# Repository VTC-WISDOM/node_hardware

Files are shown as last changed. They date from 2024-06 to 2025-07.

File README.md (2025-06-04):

# hardware
a collection of schematic and pcb designs for the WiSDOM node
unless otherwise specified, everything contained in this repository is licensed under the CERN Open Hardware License version 2 - Weakly Reciprocal License (CERN-OHL-W).
this is comparable to the gpl2, see LICENSE for details

## Using this repo
using your favorite package manager, install kicad-footprints and kicad-symbols alongside kicad. this is the best way to get the standard libraries. if you for some reason cannot do so, see the linked official kicad libraries in kicad-libs/footprints and kicad-libs/symbols.
in the kicad symbol editor, go to preferences -> manage symbol libraries and select "add existing", navigate to the kicad-libs/symbols directory and select the symbol libraries contained therein. repeat this with the symbols contained in kicad-libs/JLCPCB-Kicad-Library.
repeat this for footprints.

### node-rp2040
stores all of the relevant design files for the WiSDOM node that is based on the RP2040

### node-rp2350
like above but the RP2350

### other
test projects, antenna and transmission equipment, etc. anything unspecified

### docs
will add as much documentation as possible!

## Node V6 (RP2040)

changes:
- removed 5v regulator
- changed rp2040 xtal to the recommended part due to availability
- changed the sim card slot due to availability
- reviewed other parts and made changes to ensure full availability from both JLC and Digikey
- changed footprints over to JLC library footprints
- major layout changes- pin headers now broken out in two halves, etc - look at the pcb for a full description
- removed jst connectors (evil) and replaced them with barrel jacks
- mounting holes now m2.5 instead of m2

## Node V5 (RP2040)
 ***SIM7080G NON-FUNCTIONAL***

change since previous version:
- added USBLC6 esd protection on the usb line
- added CAT24 eeprom ic
- removed options for rtc to stick with just the PCF8523
- added SP3485 for RS485 / MODBUS communication
- added u.fl connector for the ism radio
- changed to narrower profile pushbuttons for run/bootsel
- added additional reset switch to interrupt 3.3V to the board entirely (used to reset the device to a known state for all components including the radios)
- yet more improvements to routing
- updated design to be mostly assembled by JLC pcb fab available components

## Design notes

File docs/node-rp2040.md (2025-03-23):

## V4
v4.0.2: schematic split into sheets for organization
        added better switching circuit for usb/bat operation. replaced 3.3V supply with a linear regulator for stability and reverse voltage protection. 
        includes first prototype of footprints for cellular interface. cellular functionality is not guaranteed until further testing.
        better layout of RP2040 traces. added jst connectors for battery and external power(labeled solar).  
        only "v4\_0\_2" files will be tested. assume others should not be used.

## V3
v3.0: never built. don't use.
v3.1: discovered issue with RP2040 crystal, requiring 1k series resistance
v3.2: discovered issue with switching between external and battery power causing the RP2040 to enter a locked state.
      troubleshooted MCP7940 RTC and determined it will not communicate with the RP2040 for unknown reasons
      added 5.1k resistors on usb-c cc lines
      battery & power circuitry is insufficient and risks damaging pc usb outputs if battery is reversed. no overcharge protection
      retired, do not use

## V2
v2: second prototype, used only for testing radio communications. 
    retired, do not use

## V1
v1: initial prototype. retired, do not use

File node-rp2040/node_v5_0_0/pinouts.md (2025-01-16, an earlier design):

| RP2040 GPIO | External Connection | Function/Peripheral | Remarks |
| --- | --- | --- | --- |
| 0 | | SIM7080G TX0 | |
| 1 | | SIM7080G RX0 | |
| 2 | | PCF8523 MFP1 | |
| 3 | | PCF8523 MFP2 | |
| 4 | SDA | I2C0 SDA | RTC & EEPROM on this i2c |
| 5 | SCL | I2C0 SCL | RTC & EEPROM on this i2c |
| 6 | | SP3485 DE | |
| 7 | | SP3485 !RE | |
| 8 | TX1 | SP3485 DI | sp3485 on this uart |
| 9 | RX1 | SP3485 RO | sp3485 on this uart |
| 10 | | RFM69 DIO0 | |
| 11 | | RFM69 DIO1 | |
| 12 | | | not connected. |
| 13 | | 5V REG ENABLE | |
| 14 | | SIM7080G PWRKEY | |
| 15 | | SIM7080G DTR | |
| 16 | MISO | SPI0 MISO | |
| 17 | | RFM69 CS | |
| 18 | CLK | SPI0 CLK | |
| 19 | MOSI | SPI0 MOSI | |
| 20 | | RFM69 RST | |
| 21 | CS | | can be any GPIO func. |
| 22 | | RFM69 DIO2 | |
| 23 | | RFM69 DIO3 | |
| 24 | | RFM69 DIO4 | |
| 25 | | RFM69 DIO5 | |
| 26 | | VBAT SAMPLE | 1/2 voltage divider from VBAT |
| 27 | GP27 (ADC1) | | |
| 28 | GP28 (ADC2) | | |
| 29 | GP29 (ADC3) | | |

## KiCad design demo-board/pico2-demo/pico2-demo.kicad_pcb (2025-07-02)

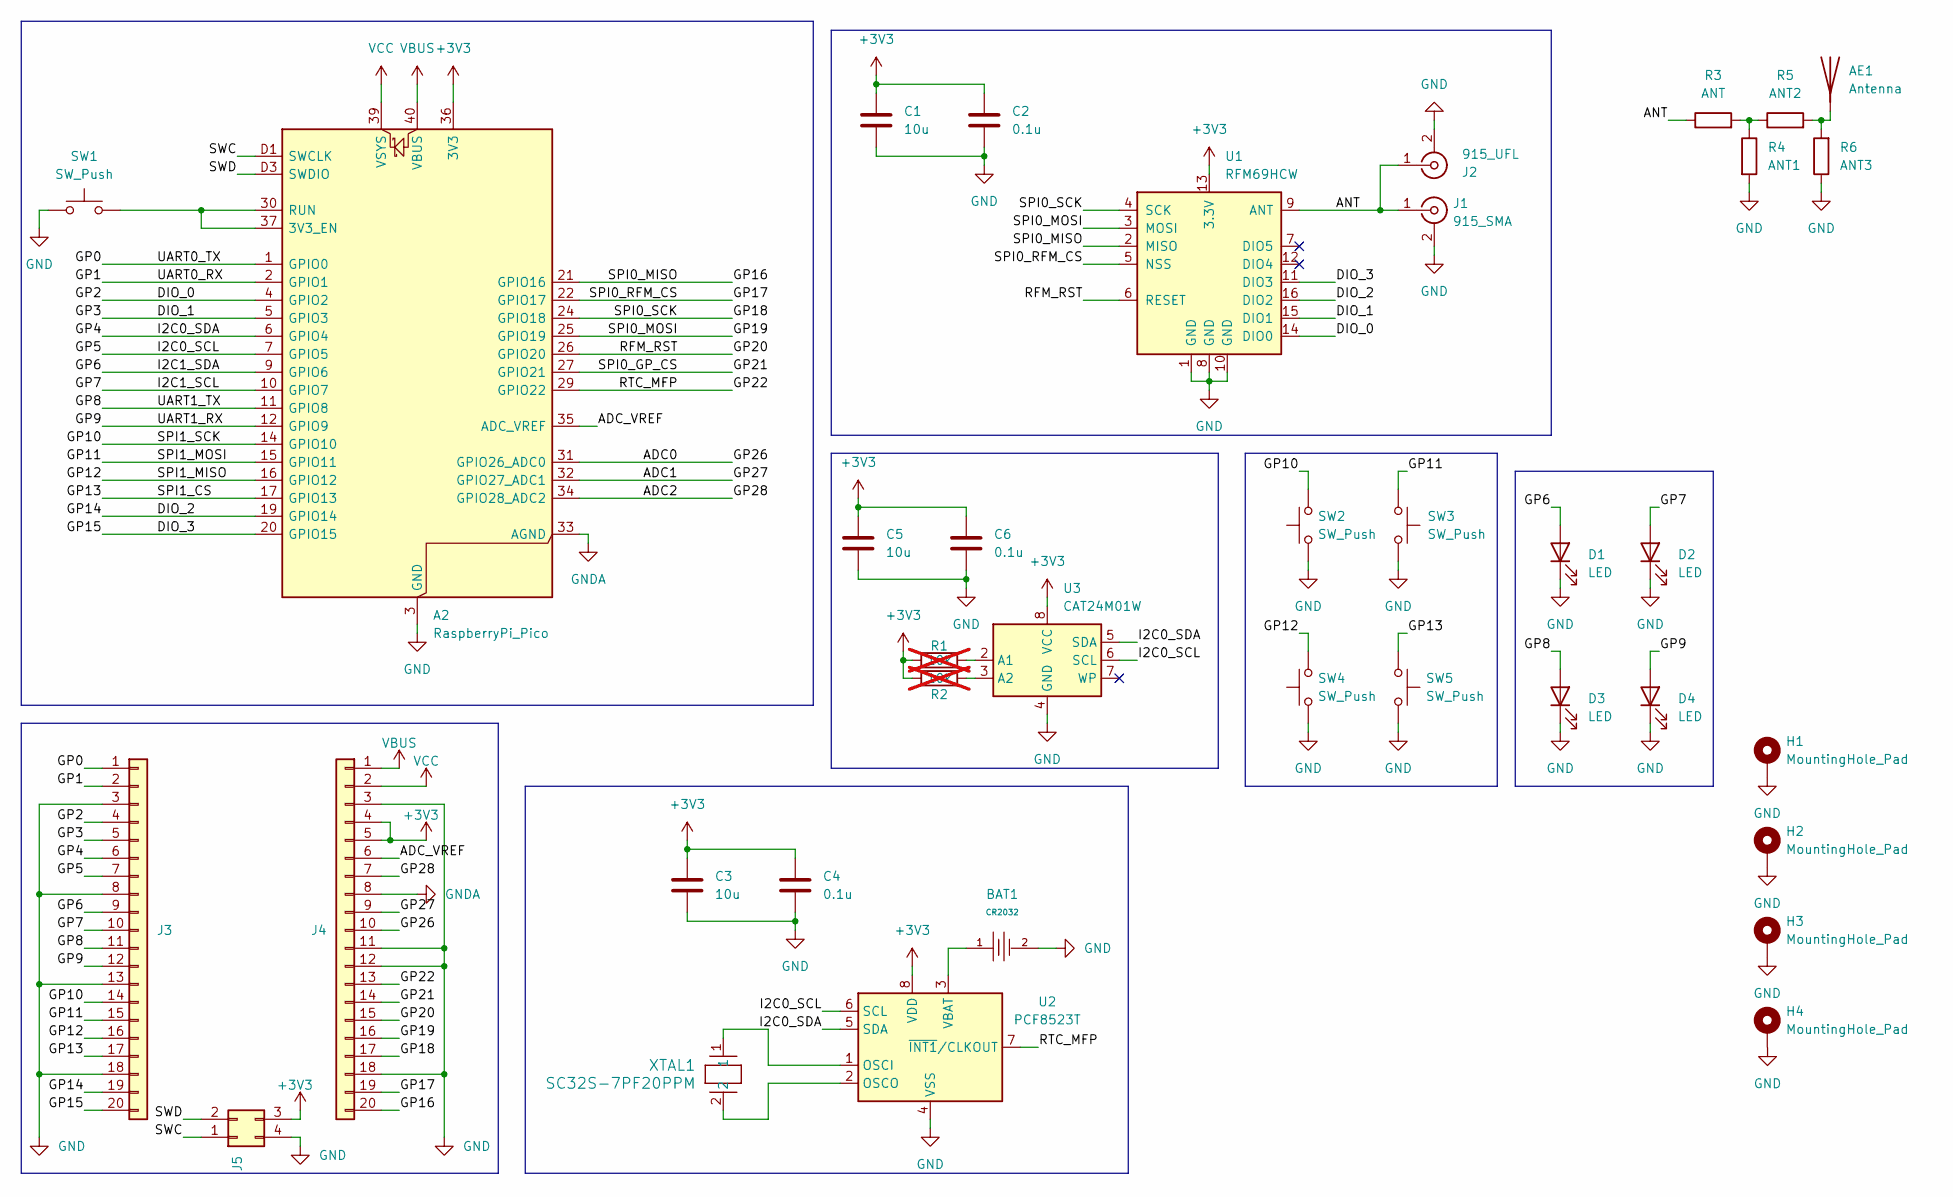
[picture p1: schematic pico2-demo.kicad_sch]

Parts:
A2: RaspberryPi_Pico; RaspberryPi_Pico_SMD_HandSolder
AE1: Antenna; Texas_SWRA416_868MHz_915MHz
BAT1: CR2032; BAT_BAT-HLD-001-THM; Part BS-07-A1BJ001; LCSC C2979167
C1, C3, C5: 10u; C_0805_2012Metric_Pad1.18x1.45mm_HandSolder
C2, C4, C6: 0.1u; C_0402_1005Metric_Pad0.74x0.62mm_HandSolder
D1, D2, D3, D4: LED; LED_1206_3216Metric_Pad1.42x1.75mm_HandSolder
H1, H2, H3: MountingHole_Pad; MountingHole_3.2mm_M3_Pad
H4: MountingHole_Pad; MountingHole_3.2mm_M3
J1: 915_SMA; SMA_Samtec_SMA-J-P-H-ST-EM1_EdgeMount
J2: 915_UFL; U.FL_Molex_MCRF_73412-0110_Vertical
J3, J4: Conn_01x20; PinHeader_1x20_P2.54mm_Vertical
J5: Conn_02x02_Counter_Clockwise; PinHeader_2x02_P2.54mm_Vertical
R1, R2: 10k; R_0805_2012Metric_Pad1.20x1.40mm_HandSolder; not fitted
R3: ANT; R_0805_2012Metric_Pad1.20x1.40mm_HandSolder
R4: ANT1; C_0402_1005Metric_Pad0.74x0.62mm_HandSolder
R5: ANT2; C_0402_1005Metric_Pad0.74x0.62mm_HandSolder
R6: ANT3; C_0402_1005Metric_Pad0.74x0.62mm_HandSolder
SW1, SW2, SW3, SW4, SW5: SW_Push; SW_PUSH_6mm
U1: RFM69HCW; HOPERF_RFM9XW_SMD
U2: PCF8523T; SOIC-8_3.9x4.9mm_P1.27mm
U3: CAT24M01W; SOIC-8_3.9x4.9mm_P1.27mm
XTAL1: SC32S-7PF20PPM; XTAL_SC32S-7PF20PPM_EPS

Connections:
+3V3: A2.36 (3V3), C1.1, C2.1, C3.1, C4.1, C5.1, C6.1, J4.4, J4.5, J5.3, R1.1, R2.1, U1.13 (3.3V), U2.8 (VDD), U3.8 (VCC)
/ADC0: A2.31 (GPIO26_ADC0), J4.10
/ADC1: A2.32 (GPIO27_ADC1), J4.9
/ADC2: A2.34 (GPIO28_ADC2), J4.7
/ADC_VREF: A2.35 (ADC_VREF), J4.6
/ANT: J1.1 (In), J2.1 (In), R3.1, U1.9 (ANT)
/DIO_0: A2.4 (GPIO2), J3.4, U1.14 (DIO0)
/DIO_1: A2.5 (GPIO3), J3.5, U1.15 (DIO1)
/DIO_2: A2.19 (GPIO14), J3.19, U1.16 (DIO2)
/DIO_3: A2.20 (GPIO15), J3.20, U1.11 (DIO3)
/GP0: A2.1 (GPIO0), J3.1
/GP1: A2.2 (GPIO1), J3.2
/GP4: A2.6 (GPIO4), J3.6, U2.5 (SDA), U3.5 (SDA)
/GP5: A2.7 (GPIO5), J3.7, U2.6 (SCL), U3.6 (SCL)
/GP6: A2.9 (GPIO6), D1.2 (A), J3.9
/GP7: A2.10 (GPIO7), D2.2 (A), J3.10
/GP8: A2.11 (GPIO8), D3.2 (A), J3.11
/GP9: A2.12 (GPIO9), D4.2 (A), J3.12
/GP10: A2.14 (GPIO10), J3.14, SW2.2
/GP11: A2.15 (GPIO11), J3.15, SW3.1
/GP12: A2.16 (GPIO12), J3.16, SW4.2
/GP13: A2.17 (GPIO13), J3.17, SW5.1
/GP16: A2.21 (GPIO16), J4.20, U1.2 (MISO)
/GP17: A2.22 (GPIO17), J4.19, U1.5 (NSS)
/GP18: A2.24 (GPIO18), J4.17, U1.4 (SCK)
/GP19: A2.25 (GPIO19), J4.16, U1.3 (MOSI)
/GP20: A2.26 (GPIO20), J4.15, U1.6 (RESET)
/GP21: A2.27 (GPIO21), J4.14
/GP22: A2.29 (GPIO22), J4.13, U2.7 (~INT1/CLKOUT)
/SWC: A2.D1 (SWCLK), J5.1
/SWD: A2.D3 (SWDIO), J5.2
GND: A2.3 (GND), A2.8 (GND), A2.13 (GND), A2.18 (GND), A2.23 (GND), A2.28 (GND), A2.38 (GND), A2.D2 (GND), BAT1.2, C1.2, C2.2, C3.2, C4.2, C5.2, C6.2, D1.1 (K), D2.1 (K), D3.1 (K), D4.1 (K), H1.1, H2.1, H3.1, J1.2 (Ext), J2.2 (Ext), J3.3, J3.8, J3.13, J3.18, J4.3, J4.11, J4.12, J4.18, J5.4, R4.2, R6.1, SW1.1, SW2.1, SW3.2, SW4.1, SW5.2, U1.1 (GND), U1.8 (GND), U1.10 (GND), U2.4 (VSS), U3.4 (GND)
GNDA: A2.33 (AGND), J4.8
unnamed: A2.30 (RUN), A2.37 (3V3_EN), SW1.2
unnamed: AE1.1 (A), R5.2, R6.2
unnamed: R3.2, R4.1, R5.1
unnamed: U2.1 (OSCI), XTAL1.1
unnamed: U2.2 (OSCO), XTAL1.2
unnamed: BAT1.1, U2.3 (VBAT)
unnamed: R1.2, U3.2 (A1)
unnamed: R2.2, U3.3 (A2)
VBUS: A2.40 (VBUS), J4.1
VCC: A2.39 (VSYS), J4.2

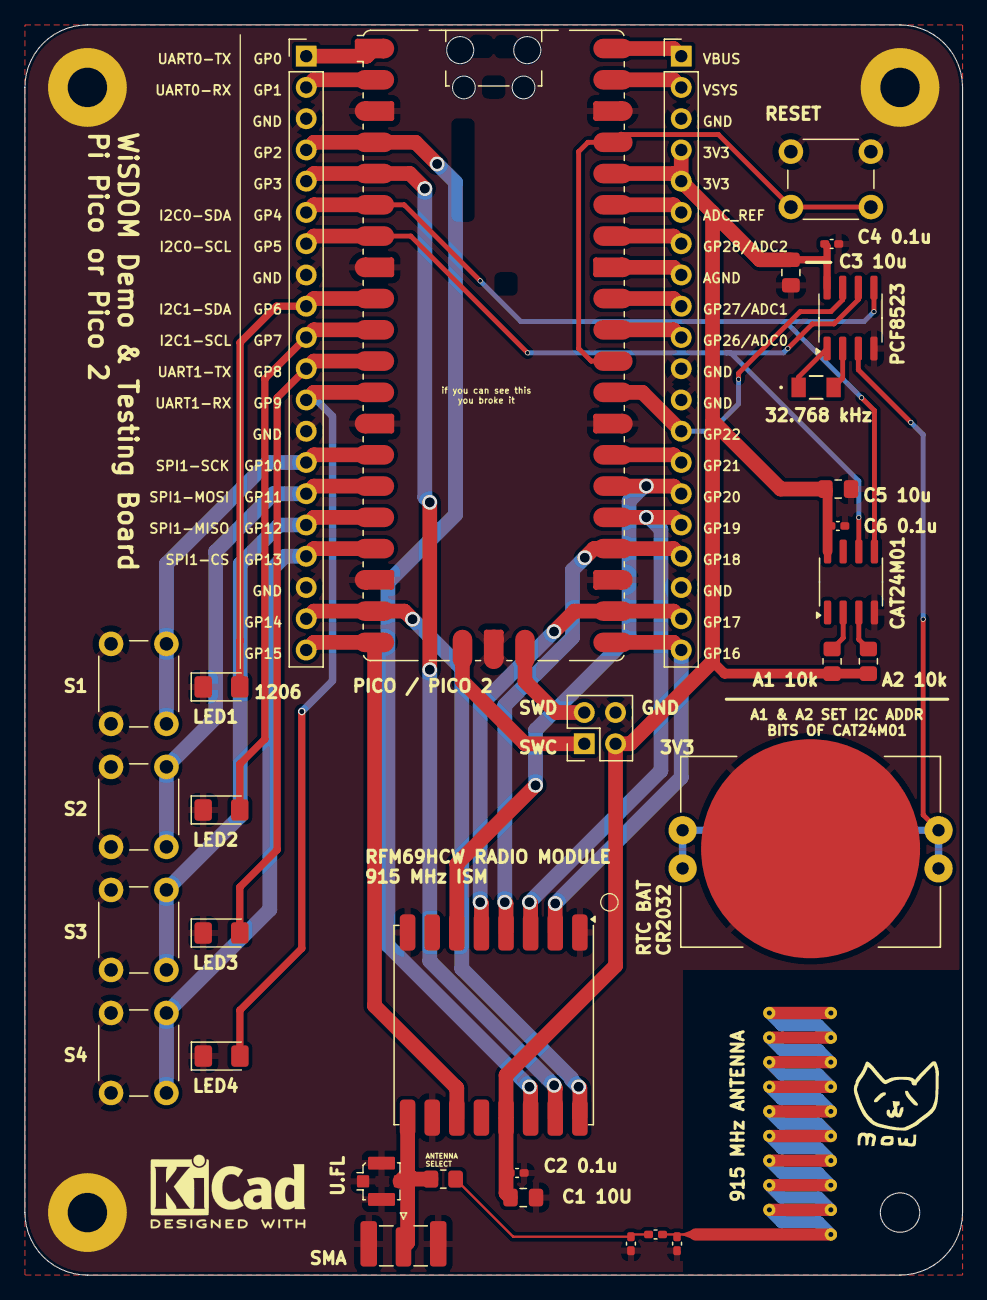
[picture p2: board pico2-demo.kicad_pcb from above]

Board: 2 copper layers, 76.2 x 101.6 mm, 37 parts (0 on the bottom side), 43 nets.

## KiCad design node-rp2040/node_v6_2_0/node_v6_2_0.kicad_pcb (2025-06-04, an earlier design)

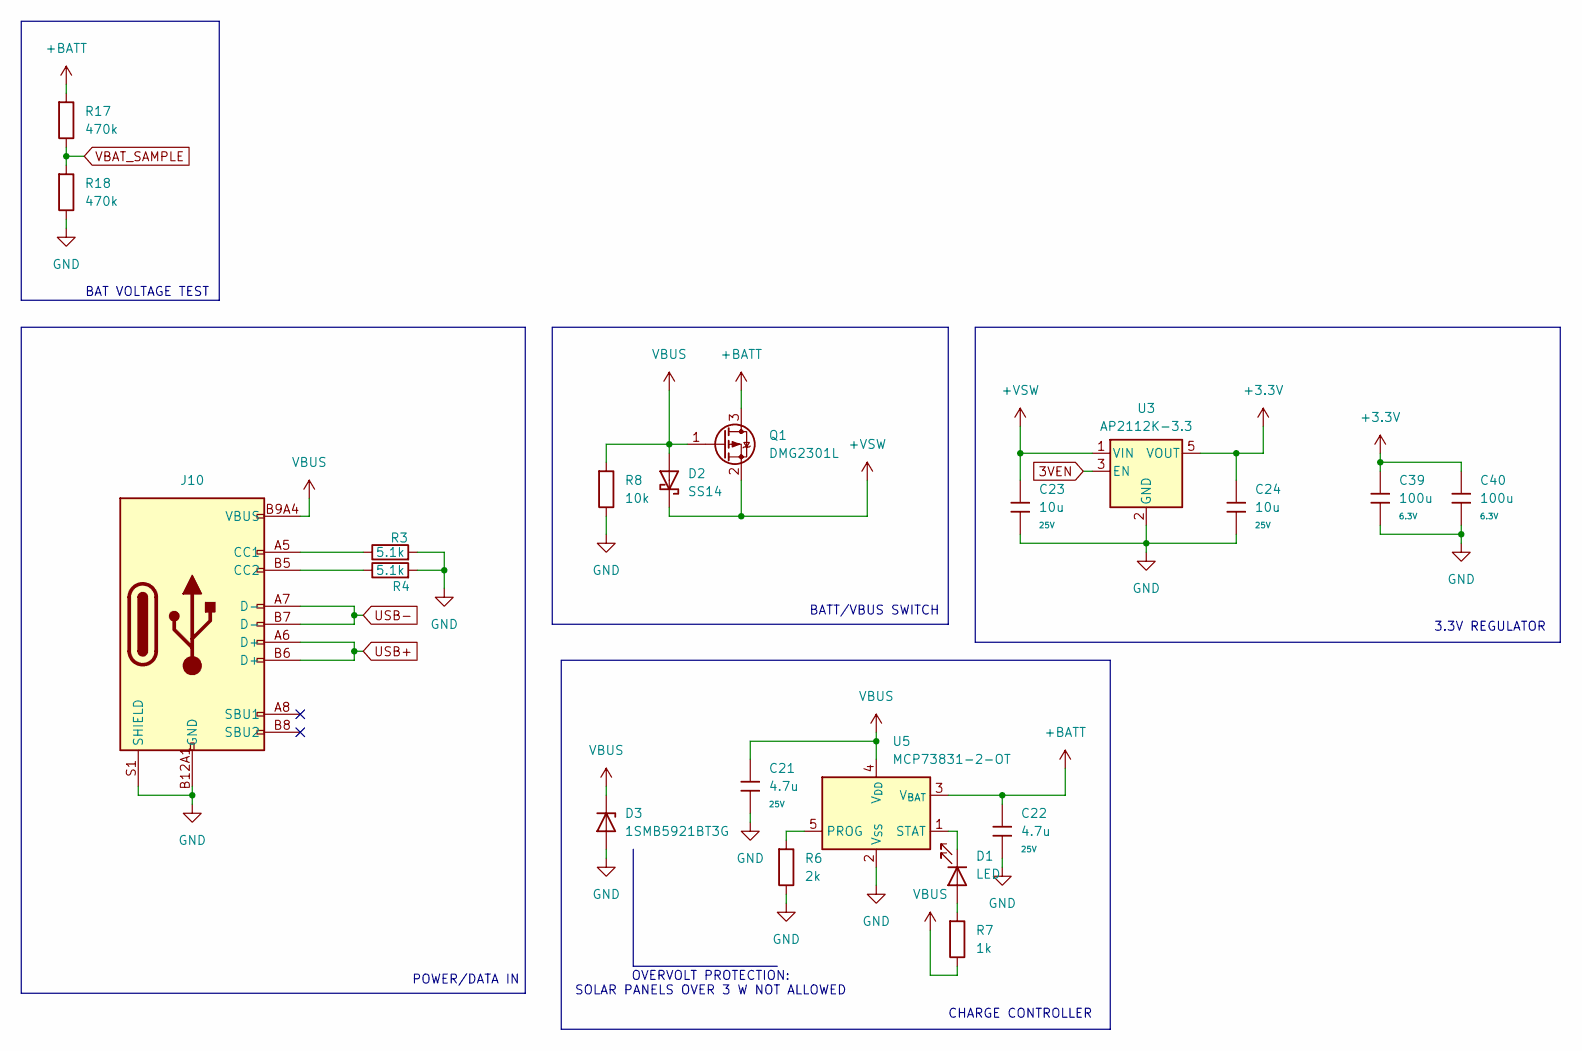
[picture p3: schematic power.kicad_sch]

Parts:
C21, C22: 4.7u; C_0805; Voltage Rated 25V; Tolerance ±10%; Part CL21A475KAQNNNE; LCSC C1779
C23, C24: 10u; C_0805; Voltage Rated 25V; Tolerance ±10%; Part CL21A106KAYNNNE; LCSC C15850
C39, C40: 100u; C_0805; Voltage Rated 6.3V; Tolerance ±20%; Part CL21A476MQYNNNE; LCSC C16780
D1: LED; LED_1206_3216Metric_Pad1.42x1.75mm_HandSolder
D2: SS14; D_SMA; Forward Voltage (Vf@If) 550mV@1A; Reverse Voltage (Vr) 40V; Part SS14; LCSC C2480
D3: 1SMB5921BT3G; D_SMB
J10: Connector, USB-TYPE-C-16P; TYPE-C-SMD_HX-TYPE-C-16PIN; LCSC C2927039
Q1: DMG2301L; D_SOT-23
R3, R4: 5.1k; R_0603
R6: 2k; R_0805; Overload Voltage (Max) 150V; Tolerance ±1%; Part 0805W8F2001T5E; LCSC C17604
R7: 1k; R_0805; Overload Voltage (Max) 150V; Tolerance ±1%; Part 0805W8F1001T5E; LCSC C17513
R8: 10k; R_0603; Overload Voltage (Max) 150V; Tolerance ±1%; Part 0805W8F1002T5E; LCSC C17414
R17, R18: 470k; R_0603; Overload Voltage (Max) 150V; Tolerance ±1%; Part 0805W8F4703T5E; LCSC C17709
U3: AP2112K-3.3; SOT-23-5_L3.0-W1.7-P0.95-LS2.8-BL
U5: MCP73831-2-OT; SOT-23-5_L3.0-W1.7-P0.95-LS2.8-BL

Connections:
3VEN: U3.3 (EN); also elsewhere on the board
+3.3V: C24.1, C39.1, C40.1, U3.5 (VOUT); also elsewhere on the board
+BATT: C22.1, Q1.3 (D), R17.1, U5.3 (V_{BAT}); also elsewhere on the board
+VSW: C23.1, D2.1, Q1.2 (S), U3.1 (VIN); also elsewhere on the board
GND: C21.2, C22.2, C23.2, C24.2, C39.2, C40.2, D3.2 (A), J10.A12B1 (GND), J10.B12A1 (GND), J10.S1 (SHIELD), R3.2, R4.2, R6.2, R8.2, R18.2, U3.2 (GND), U5.2 (V_{SS}); also elsewhere on the board
unnamed: D1.2 (A), R7.1
unnamed: D1.1 (K), U5.1 (STAT)
unnamed: J10.A5 (CC1), R3.1
unnamed: J10.B5 (CC2), R4.1
unnamed: R6.1, U5.5 (PROG)
USB+: J10.A6 (D+), J10.B6 (D+); also elsewhere on the board
USB-: J10.A7 (D-), J10.B7 (D-); also elsewhere on the board
VBAT_SAMPLE: R17.2, R18.1; also elsewhere on the board
VBUS: C21.1, D2.2, D3.1 (K), J10.A9B4 (VBUS), J10.B9A4 (VBUS), Q1.1 (G), R7.2, R8.1, U5.4 (V_{DD}); also elsewhere on the board

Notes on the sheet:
POWER/DATA IN
BATT/VBUS SWITCH
BAT VOLTAGE TEST
OVERVOLT PROTECTION: SOLAR PANELS OVER 3 W NOT ALLOWED
3.3V REGULATOR
CHARGE CONTROLLER

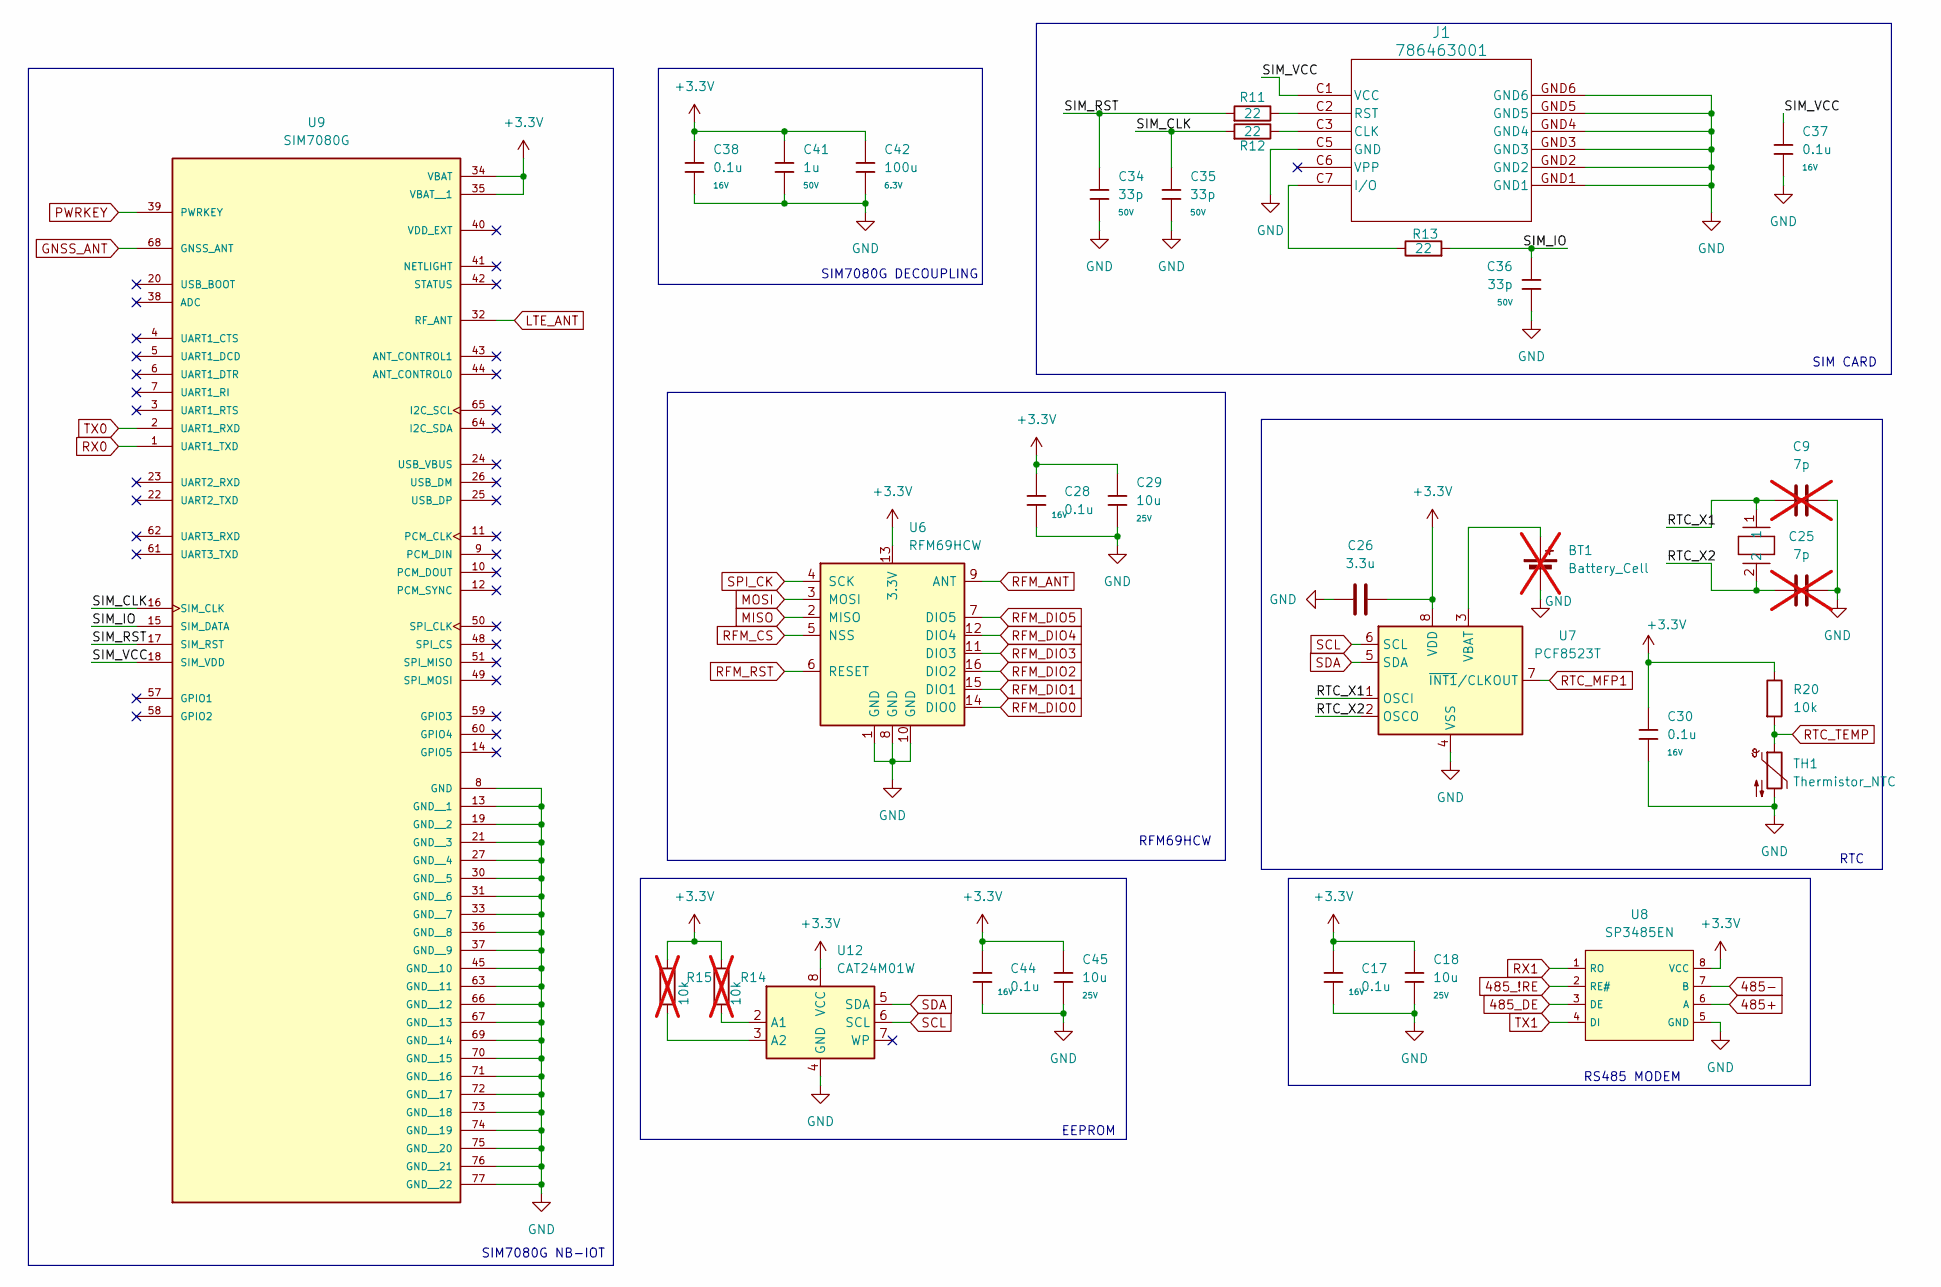
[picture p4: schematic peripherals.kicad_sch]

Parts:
BT1: Battery_Cell; BAT_BAT-HLD-001-THM; not fitted
C9, C25: 7p; C_0402; not fitted
C17, C28, C30, C37, C38, C44: 0.1u; C_0402; Voltage Rated 16V; Tolerance ±10%; Part CL05B104KO5NNNC; LCSC C1525
C18, C29, C45: 10u; C_0805; Voltage Rated 25V; Tolerance ±10%; Part CL21A106KAYNNNE; LCSC C15850
C26: 3.3u; C_0805
C34, C35, C36: 33p; C_0402; Voltage Rated 50V; Tolerance ±5%; Part 0402CG330J500NT; LCSC C1562
C41: 1u; C_0805; Voltage Rated 50V; Tolerance ±10%; Part CL21B105KBFNNNE; LCSC C28323
C42: 100u; C_0805; Voltage Rated 6.3V; Tolerance ±20%; Part CL21A476MQYNNNE; LCSC C16780
J1: 786463001; 78646-3001_MOL
R11, R12, R13: 22; R_0402; Overload Voltage (Max) 50V; Tolerance ±1%; Part 0402WGF220JTCE; LCSC C25092
R14, R15: 10k; R_0402; not fitted
R20: 10k; R_0402
TH1: Thermistor_NTC; R_0402
U6: RFM69HCW; HOPERF_RFM9XW_SMD
U7: PCF8523T; SOIC-8_3.9x4.9mm_P1.27mm
U8: SP3485EN; SOIC-8_L5.0-W4.0-P1.27-LS6.0-BL; Supply Voltage 3.3V; Part SP3485EN-L/TR; LCSC C8963
U9: SIM7080G; XCVR_SIM7080G; PARTREV 1.04
U12: CAT24M01W; SOIC-8_3.9x4.9mm_P1.27mm
XTAL1: SC32S-7PF20PPM; XTAL_SC32S-7PF20PPM_EPS

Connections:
485+: U8.6 (A); also elsewhere on the board
485-: U8.7 (B); also elsewhere on the board
485_!RE: U8.2 (RE#); also elsewhere on the board
485_DE: U8.3 (DE); also elsewhere on the board
+3.3V: C17.1, C18.1, C26.2, C28.1, C29.1, C30.1, C38.1, C41.1, C42.1, C44.1, C45.1, R14.1, R15.1, R20.1, U6.13 (3.3V), U7.8 (VDD), U8.8 (VCC), U9.34 (VBAT), U9.35 (VBAT__1), U12.8 (VCC); also elsewhere on the board
/PERIPHERALS/RTC_X1: C9.1, U7.1 (OSCI), XTAL1.1
/PERIPHERALS/RTC_X2: C25.1, U7.2 (OSCO), XTAL1.2
/PERIPHERALS/SIM_CLK: C35.1, R12.1, U9.16 (SIM_CLK)
/PERIPHERALS/SIM_IO: C36.1, R13.1, U9.15 (SIM_DATA)
/PERIPHERALS/SIM_RST: C34.1, R11.1, U9.17 (SIM_RST)
/PERIPHERALS/SIM_VCC: C37.1, J1.C1 (VCC), U9.18 (SIM_VDD)
GND: BT1.2 (-), C9.2, C17.2, C18.2, C25.2, C26.1, C28.2, C29.2, C30.2, C34.2, C35.2, C36.2, C37.2, C38.2, C41.2, C42.2, C44.2, C45.2, J1.C5 (GND), J1.GND1, J1.GND2, J1.GND3, J1.GND4, J1.GND5, J1.GND6, TH1.2, U6.1 (GND), U6.8 (GND), U6.10 (GND), U7.4 (VSS), U8.5 (GND), U9.8 (GND), U9.13 (GND__1), U9.19 (GND__2), U9.21 (GND__3), U9.27 (GND__4), U9.30 (GND__5), U9.31 (GND__6), U9.33 (GND__7), U9.36 (GND__8), U9.37 (GND__9), U9.45 (GND__10), U9.63 (GND__11), U9.66 (GND__12), U9.67 (GND__13), U9.69 (GND__14), U9.70 (GND__15), U9.71 (GND__16), U9.72 (GND__17), U9.73 (GND__18), U9.74 (GND__19), U9.75 (GND__20), U9.76 (GND__21), U9.77 (GND__22), U12.4 (GND); also elsewhere on the board
GNSS_ANT: U9.68 (GNSS_ANT); also elsewhere on the board
LTE_ANT: U9.32 (RF_ANT); also elsewhere on the board
MISO: U6.2 (MISO); also elsewhere on the board
MOSI: U6.3 (MOSI); also elsewhere on the board
unnamed: BT1.1 (+), U7.3 (VBAT)
unnamed: J1.C3 (CLK), R12.2
unnamed: J1.C7 (I/O), R13.2
unnamed: J1.C2 (RST), R11.2
unnamed: R14.2, U12.2 (A1)
unnamed: R15.2, U12.3 (A2)
PWRKEY: U9.39 (PWRKEY); also elsewhere on the board
RFM_ANT: U6.9 (ANT); also elsewhere on the board
RFM_CS: U6.5 (NSS); also elsewhere on the board
RFM_DIO0: U6.14 (DIO0); also elsewhere on the board
RFM_DIO1: U6.15 (DIO1); also elsewhere on the board
RFM_DIO2: U6.16 (DIO2); also elsewhere on the board
RFM_DIO3: U6.11 (DIO3); also elsewhere on the board
RFM_DIO4: U6.12 (DIO4); also elsewhere on the board
RFM_DIO5: U6.7 (DIO5); also elsewhere on the board
RFM_RST: U6.6 (RESET); also elsewhere on the board
RTC_MFP1: U7.7 (~INT1/CLKOUT); also elsewhere on the board
RTC_TEMP: R20.2, TH1.1; also elsewhere on the board
RX0: U9.1 (UART1_TXD); also elsewhere on the board
RX1: U8.1 (RO); also elsewhere on the board
SCL: U7.6 (SCL), U12.6 (SCL); also elsewhere on the board
SDA: U7.5 (SDA), U12.5 (SDA); also elsewhere on the board
SPI_CK: U6.4 (SCK); also elsewhere on the board
TX0: U9.2 (UART1_RXD); also elsewhere on the board
TX1: U8.4 (DI); also elsewhere on the board

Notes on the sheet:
RFM69HCW
EEPROM
SIM7080G DECOUPLING
RTC
SIM CARD
RS485 MODEM
SIM7080G NB-IOT

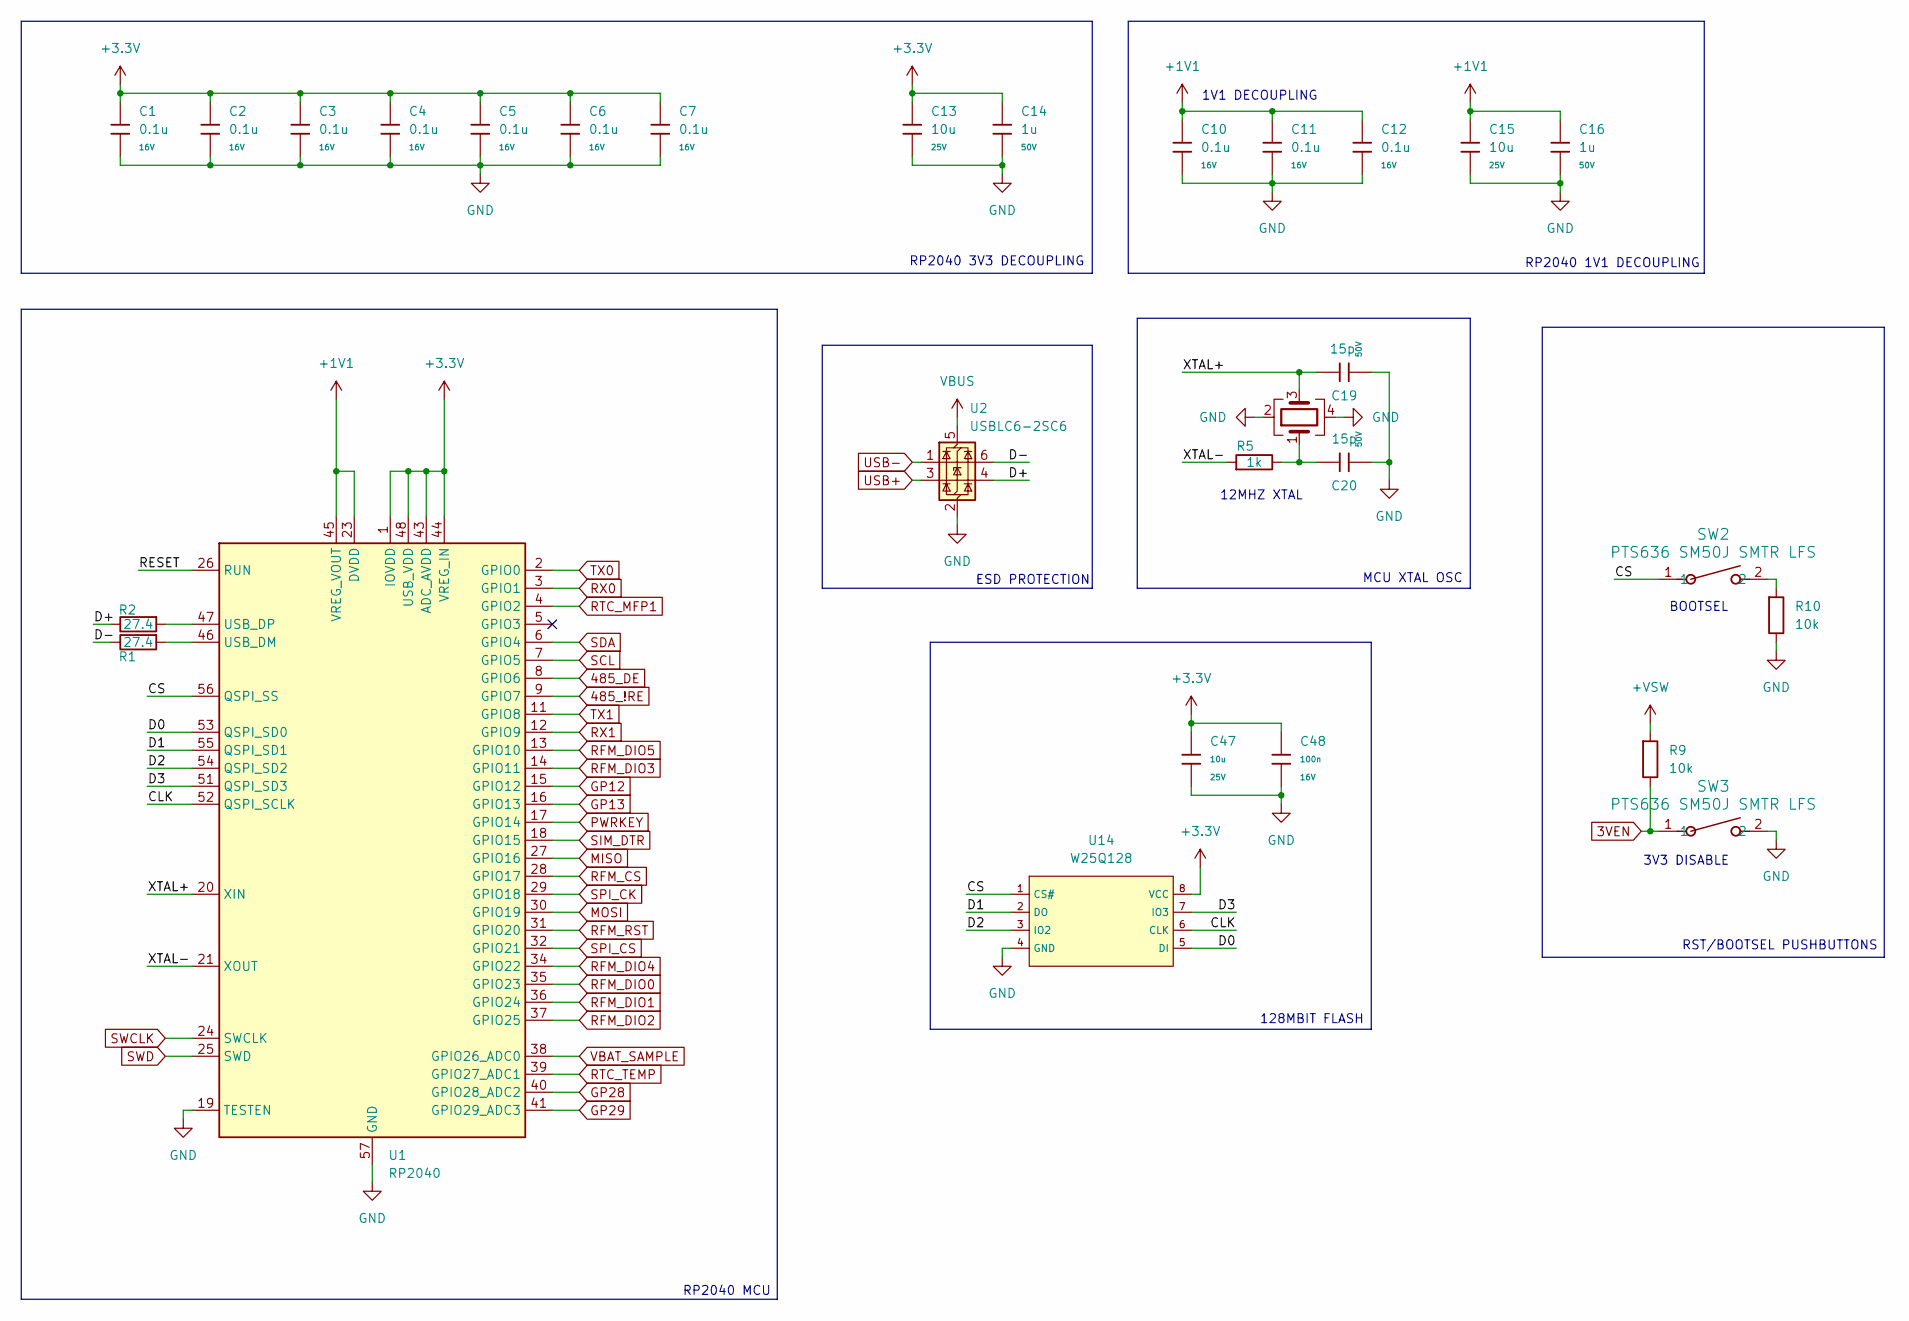
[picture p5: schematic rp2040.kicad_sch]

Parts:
C1, C2, C3, C4, C5, C6, C7, C10, C11, C12: 0.1u; C_0402; Voltage Rated 16V; Tolerance ±10%; Part CL05B104KO5NNNC; LCSC C1525
C13, C15, C47: 10u; C_0805; Voltage Rated 25V; Tolerance ±10%; Part CL21A106KAYNNNE; LCSC C15850
C14, C16: 1u; C_0805; Voltage Rated 50V; Tolerance ±10%; Part CL21B105KBFNNNE; LCSC C28323
C19, C20: 15p; C_0402; Voltage Rated 50V; Tolerance ±5%; Part 0402CG150J500NT; LCSC C1548
C48: 100n; C_0402; Voltage Rated 16V; Tolerance ±10%; Part CL05B104KO5NNNC; LCSC C1525
R1, R2: 27.4; R_0603; Overload Voltage (Max) 75V; Tolerance ±1%; Part 0603WAF270JT5E; LCSC C25190
R5: 1k; R_0402; Overload Voltage (Max) 150V; Tolerance ±1%; Part 0805W8F1001T5E; LCSC C17513
R9, R10: 10k; R_0805; Overload Voltage (Max) 150V; Tolerance ±1%; Part 0805W8F1002T5E; LCSC C17414
SW2, SW3: PTS636 SM50J SMTR LFS; SW_PTS636_CNK
U1: RP2040; QFN-56-1EP_7x7mm_P0.4mm_EP3.2x3.2mm_ThermalVias; LCSC C2040
U2: USBLC6-2SC6; SOT-23-6_L2.9-W1.6-P0.95-LS2.8-BL
U14: W25Q128; SOIC-8_L5.3-W5.3-P1.27-LS8.0-BL; Part W25Q128JVSIQ; LCSC C97521
Y1: ABM8-272-T3; CRYSTAL-SMD_4P-L3.2-W2.5-BL

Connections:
3VEN: R9.2, SW3.1; also elsewhere on the board
485_!RE: U1.9 (GPIO7); also elsewhere on the board
485_DE: U1.8 (GPIO6); also elsewhere on the board
+1V1: C10.1, C11.1, C12.1, C15.1, C16.1, U1.23 (DVDD), U1.45 (VREG_VOUT), U1.50 (DVDD)
+3.3V: C1.1, C2.1, C3.1, C4.1, C5.1, C6.1, C7.1, C13.1, C14.1, C47.1, C48.1, U1.1 (IOVDD), U1.10 (IOVDD), U1.22 (IOVDD), U1.33 (IOVDD), U1.42 (IOVDD), U1.43 (ADC_AVDD), U1.44 (VREG_IN), U1.48 (USB_VDD), U1.49 (IOVDD), U14.8 (VCC); also elsewhere on the board
+VSW: R9.1; also elsewhere on the board
/MCU/CLK: U1.52 (QSPI_SCLK), U14.6 (CLK)
/MCU/CS: SW2.1, U1.56 (QSPI_SS), U14.1 (CS#)
/MCU/D0: U1.53 (QSPI_SD0), U14.5 (DI)
/MCU/D1: U1.55 (QSPI_SD1), U14.2 (DO)
/MCU/D2: U1.54 (QSPI_SD2), U14.3 (IO2)
/MCU/D3: U1.51 (QSPI_SD3), U14.7 (IO3)
/MCU/D+: R2.2, U2.4 (I/O2)
/MCU/D-: R1.2, U2.6 (I/O1)
/MCU/RESET: U1.26 (RUN)
/MCU/XTAL+: C19.1, U1.20 (XIN), Y1.3
/MCU/XTAL-: R5.1, U1.21 (XOUT)
GND: C1.2, C2.2, C3.2, C4.2, C5.2, C6.2, C7.2, C10.2, C11.2, C12.2, C13.2, C14.2, C15.2, C16.2, C19.2, C20.2, C47.2, C48.2, R10.2, SW3.2, U1.19 (TESTEN), U1.57 (GND), U2.2 (GND), U14.4 (GND), Y1.2, Y1.4; also elsewhere on the board
GP12: U1.15 (GPIO12); also elsewhere on the board
GP13: U1.16 (GPIO13); also elsewhere on the board
GP28: U1.40 (GPIO28_ADC2); also elsewhere on the board
GP29: U1.41 (GPIO29_ADC3); also elsewhere on the board
MISO: U1.27 (GPIO16); also elsewhere on the board
MOSI: U1.30 (GPIO19); also elsewhere on the board
unnamed: C20.1, R5.2, Y1.1
unnamed: R10.1, SW2.2
unnamed: R1.1, U1.46 (USB_DM)
unnamed: R2.1, U1.47 (USB_DP)
PWRKEY: U1.17 (GPIO14); also elsewhere on the board
RFM_CS: U1.28 (GPIO17); also elsewhere on the board
RFM_DIO0: U1.35 (GPIO23); also elsewhere on the board
RFM_DIO1: U1.36 (GPIO24); also elsewhere on the board
RFM_DIO2: U1.37 (GPIO25); also elsewhere on the board
RFM_DIO3: U1.14 (GPIO11); also elsewhere on the board
RFM_DIO4: U1.34 (GPIO22); also elsewhere on the board
RFM_DIO5: U1.13 (GPIO10); also elsewhere on the board
RFM_RST: U1.31 (GPIO20); also elsewhere on the board
RTC_MFP1: U1.4 (GPIO2); also elsewhere on the board
RTC_TEMP: U1.39 (GPIO27_ADC1); also elsewhere on the board
RX0: U1.3 (GPIO1); also elsewhere on the board
RX1: U1.12 (GPIO9); also elsewhere on the board
SCL: U1.7 (GPIO5); also elsewhere on the board
SDA: U1.6 (GPIO4); also elsewhere on the board
SIM_DTR: U1.18 (GPIO15)
SPI_CK: U1.29 (GPIO18); also elsewhere on the board
SPI_CS: U1.32 (GPIO21); also elsewhere on the board
SWCLK: U1.24 (SWCLK); also elsewhere on the board
SWD: U1.25 (SWD); also elsewhere on the board
TX0: U1.2 (GPIO0); also elsewhere on the board
TX1: U1.11 (GPIO8); also elsewhere on the board
USB+: U2.3 (I/O2); also elsewhere on the board
USB-: U2.1 (I/O1); also elsewhere on the board
VBAT_SAMPLE: U1.38 (GPIO26_ADC0); also elsewhere on the board
VBUS: U2.5 (VBUS); also elsewhere on the board

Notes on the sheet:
RST/BOOTSEL PUSHBUTTONS
RP2040 3V3 DECOUPLING
RP2040 MCU
RP2040 1V1 DECOUPLING
BOOTSEL
3V3 DISABLE
MCU XTAL OSC
1V1 DECOUPLING
12MHZ XTAL
128MBIT FLASH
ESD PROTECTION

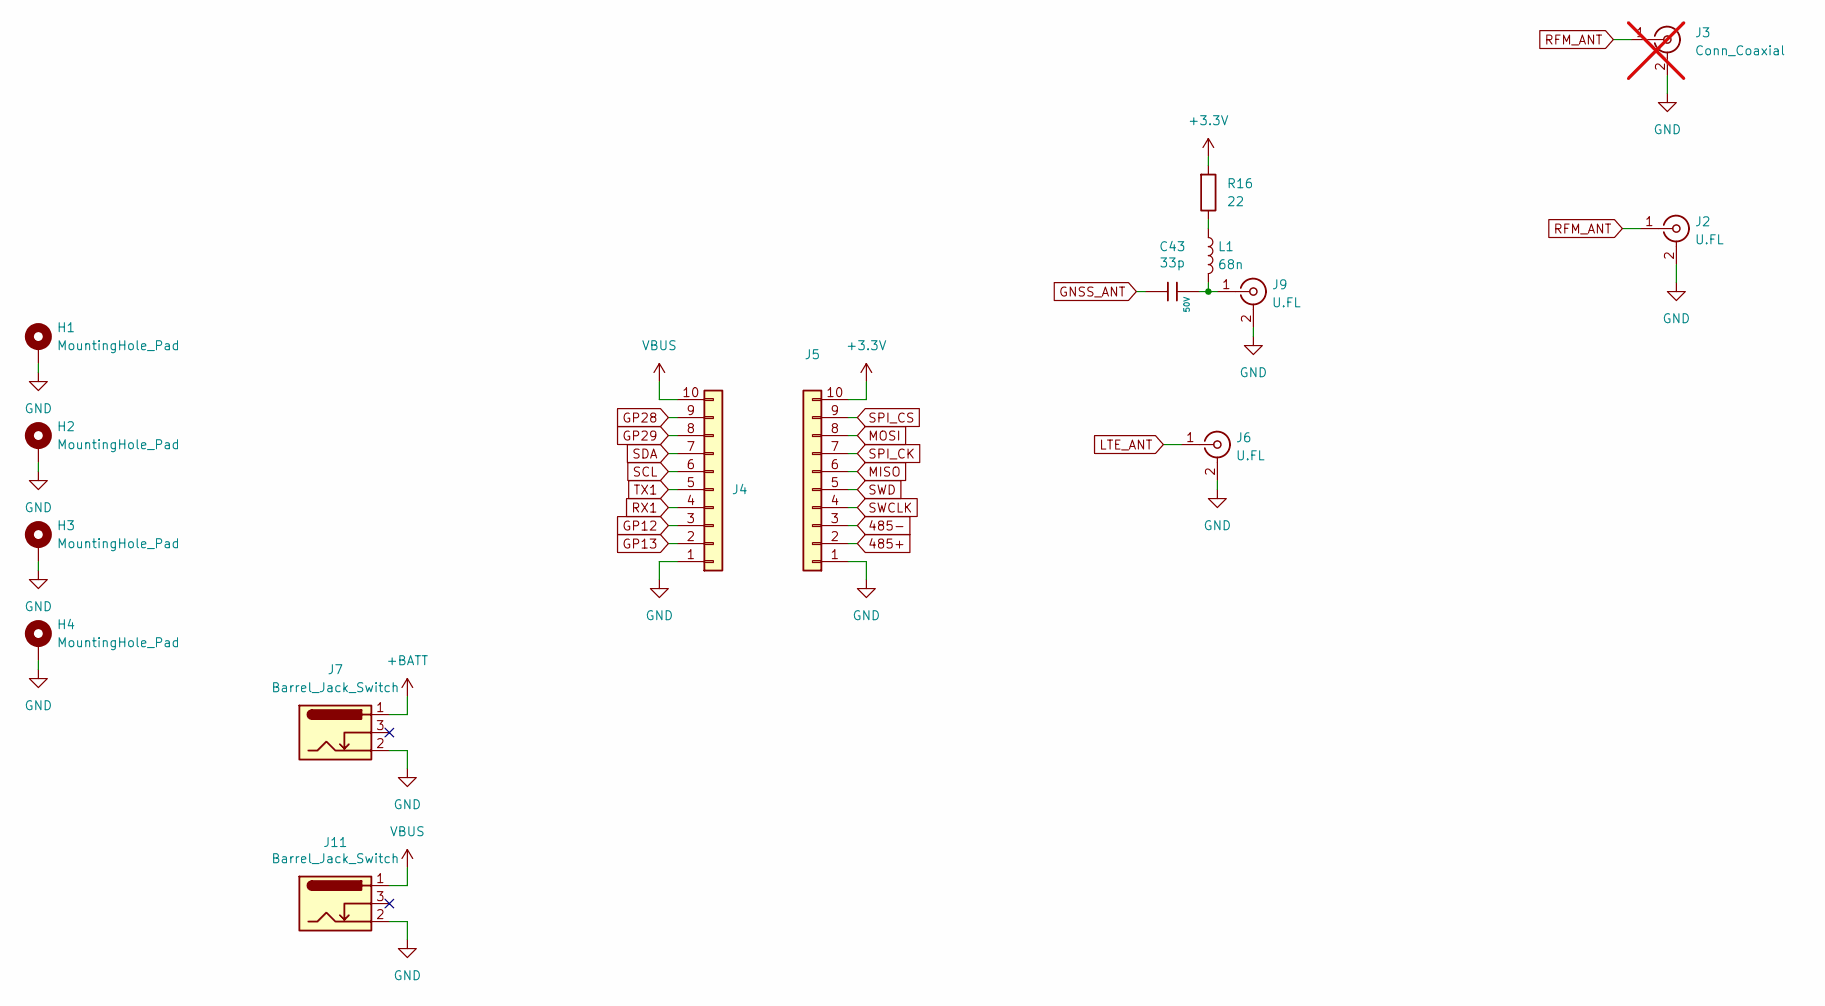
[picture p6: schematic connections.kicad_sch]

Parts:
C43: 33p; C_0402; Voltage Rated 50V; Tolerance ±5%; Part 0402CG330J500NT; LCSC C1562
H1, H2, H3, H4: MountingHole_Pad; MountingHole_2.5mm_Pad_TopBottom
J2, J6, J9: U.FL; IPEX-SMD_BWIPX-1-001E; LCSC C5137195
J3: Conn_Coaxial; SMA_Samtec_SMA-J-P-H-ST-EM1_EdgeMount; not fitted
J4, J5: Conn_01x10; PinHeader_1x10_P2.54mm_Vertical
J7, J11: Barrel_Jack_Switch; PJ-007
L1: 68n; L_0402
R16: 22; R_0402; Overload Voltage (Max) 150V; Tolerance ±1%; Part 0805W8F220JT5E; LCSC C17561

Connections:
485+: J5.2; also elsewhere on the board
485-: J5.3; also elsewhere on the board
+3.3V: J5.10, R16.1; also elsewhere on the board
+BATT: J7.1; also elsewhere on the board
GND: H1.1, H2.1, H3.1, H4.1, J2.2 (Ext), J2.3, J3.2 (Ext), J4.1, J5.1, J6.2 (Ext), J6.3, J7.2, J9.2 (Ext), J9.3, J11.2; also elsewhere on the board
GNSS_ANT: C43.1; also elsewhere on the board
GP12: J4.3; also elsewhere on the board
GP13: J4.2; also elsewhere on the board
GP28: J4.9; also elsewhere on the board
GP29: J4.8; also elsewhere on the board
LTE_ANT: J6.1 (In); also elsewhere on the board
MISO: J5.6; also elsewhere on the board
MOSI: J5.8; also elsewhere on the board
unnamed: C43.2, J9.1 (In), L1.2
unnamed: L1.1, R16.2
RFM_ANT: J2.1 (In), J3.1 (In); also elsewhere on the board
RX1: J4.4; also elsewhere on the board
SCL: J4.6; also elsewhere on the board
SDA: J4.7; also elsewhere on the board
SPI_CK: J5.7; also elsewhere on the board
SPI_CS: J5.9; also elsewhere on the board
SWCLK: J5.4; also elsewhere on the board
SWD: J5.5; also elsewhere on the board
TX1: J4.5; also elsewhere on the board
VBUS: J4.10, J11.1; also elsewhere on the board

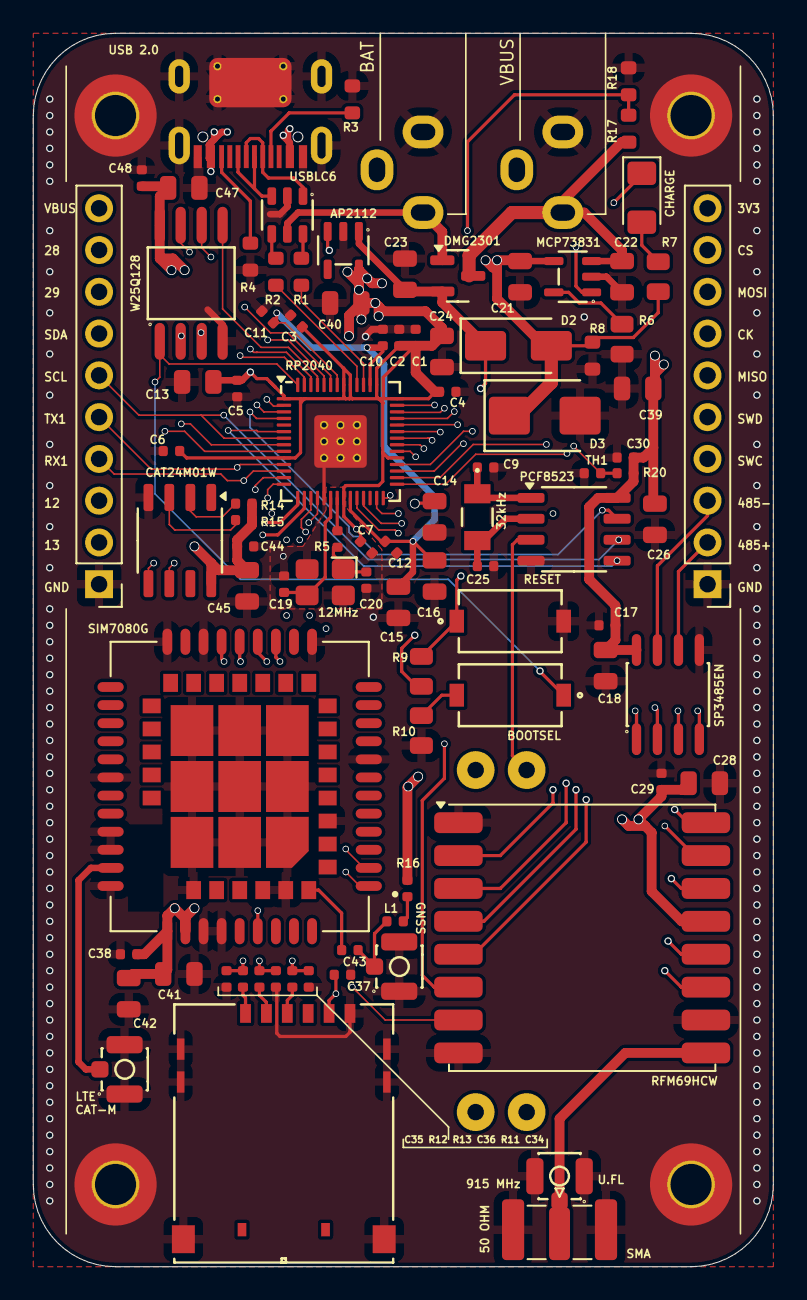
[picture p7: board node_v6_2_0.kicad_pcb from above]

Board: 6 copper layers, 45.0 x 75.0 mm, 96 parts (1 on the bottom side), 77 nets.

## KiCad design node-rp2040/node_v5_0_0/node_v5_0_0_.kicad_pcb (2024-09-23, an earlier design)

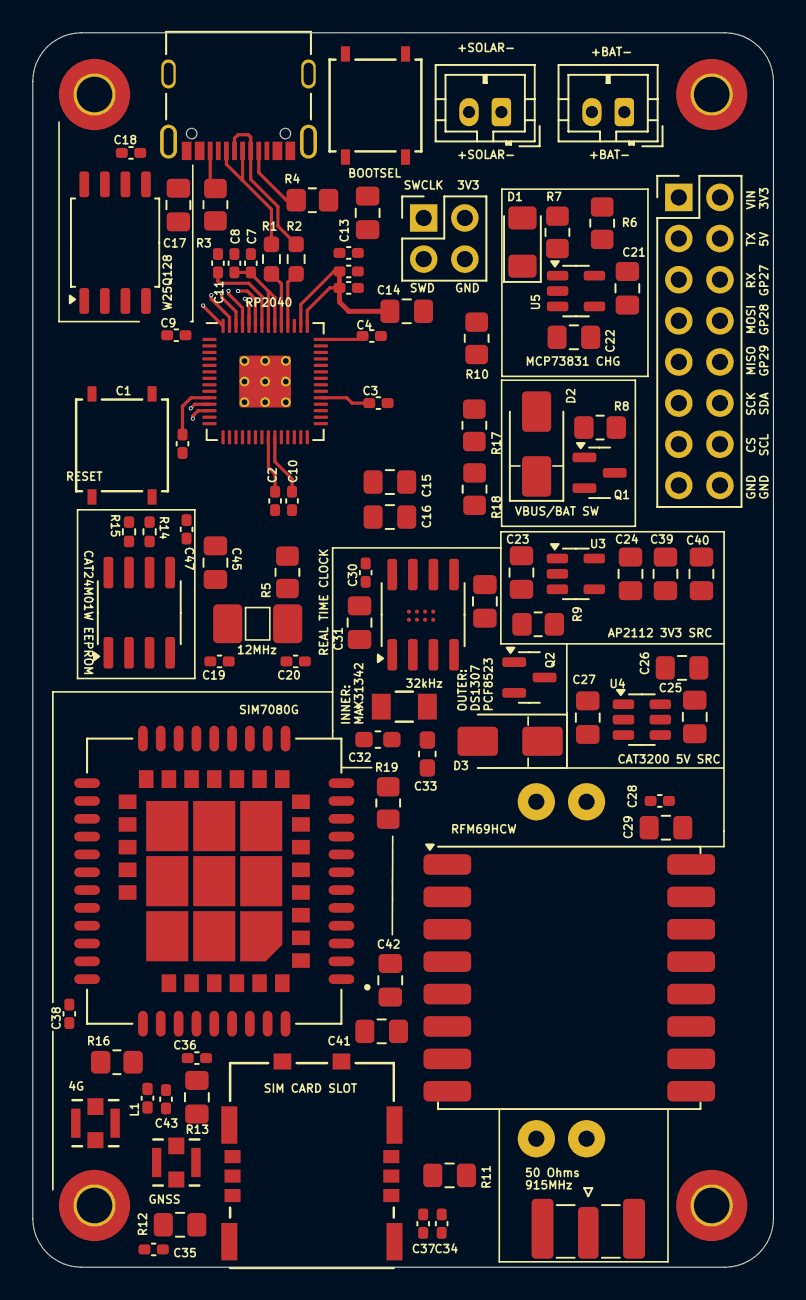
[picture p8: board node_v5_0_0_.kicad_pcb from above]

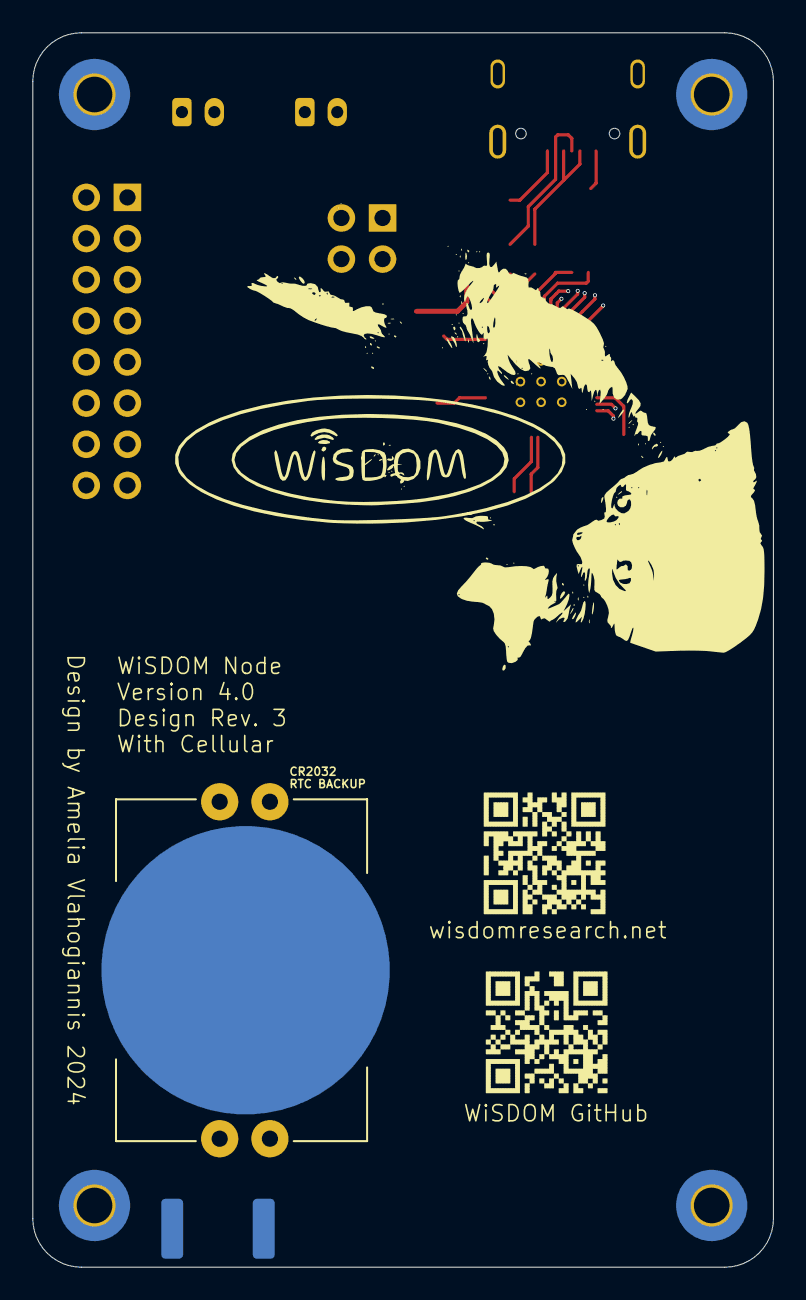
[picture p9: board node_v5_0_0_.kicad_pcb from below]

Board: 4 copper layers, 45.7 x 76.2 mm, 101 parts (3 on the bottom side), 71 nets.

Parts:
BT1: RTC_BAT; BAT_BAT-HLD-001-THM
C1, C2, C3, C4, C5, C6, C7, C8, C9, C10, C11, C12, C18, C28, C30, C37, C38, C44: 0.1u; C_0402_1005Metric_Pad0.74x0.62mm_HandSolder
C13, C15, C17, C23, C24, C29, C31, C45, C46: 10u; C_0805_2012Metric_Pad1.18x1.45mm_HandSolder
C14, C16, C25, C26, C27, C41: 1u; C_0805_2012Metric_Pad1.18x1.45mm_HandSolder
C19, C20: 15pF; C_0402_1005Metric_Pad0.74x0.62mm_HandSolder
C21, C22: 4.7u; C_0805_2012Metric_Pad1.18x1.45mm_HandSolder
C32, C33: 6p; C_0603_1608Metric_Pad1.08x0.95mm_HandSolder
C34, C35, C36, C43: 33p; C_0402_1005Metric_Pad0.74x0.62mm_HandSolder
C39, C40, C42: 100u; C_0805_2012Metric_Pad1.18x1.45mm_HandSolder
D1: LED; LED_1206_3216Metric_Pad1.42x1.75mm_HandSolder
D2, D3: SS14; D_SMA
H1, H2, H3, H4: MountingHole_Pad; MountingHole_2.2mm_M2_Pad_TopBottom
J1, J8: Conn_01x02_Pin; JST_PH_B2B-PH-K_1x02_P2.00mm_Vertical
J2: 12402012E212A; AMPHENOL_12402012E212A
J3: Conn_Coaxial; SMA_Samtec_SMA-J-P-H-ST-EM1_EdgeMount
J4: Conn_02x08_Odd_Even; PinHeader_2x08_P2.54mm_Vertical
J5: Conn_02x02_Odd_Even; PinHeader_2x02_P2.54mm_Vertical
J6: GNSS_ANT; CONN_CONMHF1-SMD_LNX
J7: RF_ANT; CONN_CONMHF1-SMD_LNX
L1: L; L_0402_1005Metric_Pad0.77x0.64mm_HandSolder
LOGO: qrcode
LOGO#2: github_qr
Q1, Q2: DMG2301L; SOT-23
R1, R2: 27.4; R_0603_1608Metric_Pad0.98x0.95mm_HandSolder
R3, R4: 5.1k; R_0805_2012Metric_Pad1.20x1.40mm_HandSolder
R5, R7: 1k; R_0805_2012Metric_Pad1.20x1.40mm_HandSolder
R6: 2k; R_0805_2012Metric_Pad1.20x1.40mm_HandSolder
R8, R10, R19: 10k; R_0805_2012Metric_Pad1.20x1.40mm_HandSolder
R9: R; R_0805_2012Metric_Pad1.20x1.40mm_HandSolder
R11, R12, R13: 22; C_0805_2012Metric_Pad1.18x1.45mm_HandSolder
R14, R15: 10k DNF; R_0402_1005Metric_Pad0.72x0.64mm_HandSolder
R16: 22; R_0805_2012Metric_Pad1.20x1.40mm_HandSolder
R17, R18: 470k; R_0805_2012Metric_Pad1.20x1.40mm_HandSolder
U1: RP2040; RP2040-QFN-56
U2: W25Q128JVS; SOIC-8_5.23x5.23mm_P1.27mm
U3: AP2112K-3.3; SOT-23-5
U4: CAT3200-5; SOT-23-6
U5: MCP73831-2-OT; SOT-23-5
U6: RFM69HCW; HOPERF_RFM9XW_SMD
U7, U8: PTS526 SK15 SMTR2 LFS; PTS526
U9: SIM7080G; XCVR_SIM7080G
U10: MCP7940 / DS1307 / PCF8523; SOIC-8_3.9x4.9mm_P1.27mm
U11: 1042240820; 1042240820_MOL
U12: CAT24M01W; SOIC-8_3.9x4.9mm_P1.27mm
U13: MAX31342EWA+T; 21-100291_W80D&plus_1_MXM
X1: XTAL-445
XTAL1: SC32S-7PF20PPM; XTAL_SC32S-7PF20PPM_EPS

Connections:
5V_CTRL: U1.16 (GPIO13), U4.3 (~SHDN)
+1V1: C10.1, C11.1, C12.1, C15.1, C16.1, U1.23 (DVDD), U1.45 (VREG_VOUT), U1.50 (DVDD)
+3.3V: C1.1, C2.1, C3.1, C4.1, C5.1, C6.1, C7.1, C8.1, C9.1, C13.1, C14.1, C17.1, C18.1, C24.1, C28.1, C29.1, C30.1, C31.1, C38.1, C39.1, C40.1, C41.1, C42.1, C44.1, C45.1, D3.2 (A), J4.2, J5.2, Q2.1 (G), R14.1, R15.1, R16.1, R19.1, U1.1 (IOVDD), U1.10 (IOVDD), U1.22 (IOVDD), U1.33 (IOVDD), U1.42 (IOVDD), U1.43 (ADC_AVDD), U1.44 (VREG_IN), U1.48 (USB_VDD), U1.49 (IOVDD), U2.8 (VCC), U3.5 (VOUT), U6.13 (3.3V), U9.34 (VBAT), U9.35 (VBAT__1), U10.8 (VCC), U12.8 (VCC)
+5V: C27.1, J4.4, U4.1 (VOUT)
+BATT: C22.1, J1.2, Q1.3 (D), R17.1, U5.3 (V_{BAT})
+VRTC: C46.1, D3.1 (K), Q2.2 (S), U13.B2 (VCC)
+VSW: C23.1, C26.1, D2.1 (K), Q1.2 (S), R9.1, U3.1 (VIN), U4.5 (VIN)
/MCU/CLK: U1.52 (QSPI_SCLK), U2.6 (CLK)
/MCU/CS: U1.56 (QSPI_SS), U2.1 (~CS), U8.1, U8.2
/MCU/D0: U1.53 (QSPI_SD0), U2.5 (DI(IO0))
/MCU/D1: U1.55 (QSPI_SD1), U2.2 (DO(IO1))
/MCU/D2: U1.54 (QSPI_SD2), U2.3 (IO2)
/MCU/D3: U1.51 (QSPI_SD3), U2.7 (IO3)
/MCU/RESET: U1.26 (RUN), U7.1, U7.2
/MCU/XTAL+: C19.1, U1.20 (XIN), X1.2
/MCU/XTAL-: R5.1, U1.21 (XOUT)
/PERIPHERALS/ANT: J3.1 (In), U6.9 (ANT)
/PERIPHERALS/RTC_X1: C32.1, U10.1 (X1), U13.A1 (X2), XTAL1.1
/PERIPHERALS/RTC_X2: C33.1, U10.2 (X2), U13.B1 (X1), XTAL1.2
/PERIPHERALS/SIM_CLK: C35.1, R12.1, U9.16 (SIM_CLK)
/PERIPHERALS/SIM_IO: C36.1, R13.1, U9.15 (SIM_DATA)
/PERIPHERALS/SIM_RST: C34.1, R11.1, U9.17 (SIM_RST)
/PERIPHERALS/SIM_VCC: C37.1, U9.18 (SIM_VDD), U11.S1 (VCC)
GND: BT1.2 (-), C1.2, C2.2, C3.2, C4.2, C5.2, C6.2, C7.2, C8.2, C9.2, C10.2, C11.2, C12.2, C13.2, C14.2, C15.2, C16.2, C17.2, C18.2, C19.2, C20.2, C21.2, C22.2, C23.2, C24.2, C26.2, C27.2, C28.2, C29.2, C30.2, C31.2, C32.2, C33.2, C34.2, C35.2, C36.2, C37.2, C38.2, C39.2, C40.2, C41.2, C42.2, C44.2, C45.2, C46.2, H1.1, H2.1, H3.1, H4.1, J1.1, J2.A1_B12 (GND), J2.B1_A12 (GND__1), J2.SH1 (SHIELD), J2.SH2 (SHIELD__1), J2.SH3 (SHIELD__2), J2.SH4 (SHIELD__3), J3.2 (Ext), J4.15, J4.16, J5.4, J6.2 (Ext), J7.2 (Ext), J8.1, R3.2, R4.2, R6.2, R8.2, R10.2, R18.2, R19.2, U1.19 (TESTEN), U1.57 (GND), U2.4 (GND), U3.2 (GND), U4.2 (GND), U5.2 (V_{SS}), U6.1 (GND), U6.8 (GND), U6.10 (GND), U7.3, U7.4, U9.8 (GND), U9.13 (GND__1), U9.19 (GND__2), U9.21 (GND__3), U9.27 (GND__4), U9.30 (GND__5), U9.31 (GND__6), U9.33 (GND__7), U9.36 (GND__8), U9.37 (GND__9), U9.45 (GND__10), U9.63 (GND__11), U9.66 (GND__12), U9.67 (GND__13), U9.69 (GND__14), U9.70 (GND__15), U9.71 (GND__16), U9.72 (GND__17), U9.73 (GND__18), U9.74 (GND__19), U9.75 (GND__20), U9.76 (GND__21), U9.77 (GND__22), U10.4 (VSS), U11.G1 (GND), U11.G2 (GND), U11.G3 (GND), U11.G4 (GND), U11.S4 (GND), U12.4 (GND), U13.A2 (GND)
GNSS_ANT: C43.1, U9.68 (GNSS_ANT)
GP27: J4.6, U1.39 (GPIO27_ADC1)
GP28: J4.8, U1.40 (GPIO28_ADC2)
GP29: J4.10, U1.41 (GPIO29_ADC3)
MISO: J4.9, U1.27 (GPIO16), U6.2 (MISO)
MOSI: J4.7, U1.30 (GPIO19), U6.3 (MOSI)
unnamed: C20.1, R5.2, X1.1
unnamed: D1.2 (A), R7.1
unnamed: D1.1 (K), U5.1 (STAT)
unnamed: J2.A5 (CC1_A), R4.1
unnamed: J2.B5 (CC1_B), R3.1
unnamed: C43.2, J6.1 (In), L1.2
unnamed: L1.1, R16.2
unnamed: R10.1, U8.3, U8.4
unnamed: R2.1, U1.46 (USB_DM)
unnamed: R1.1, U1.47 (USB_DP)
unnamed: R9.2, U3.3 (EN)
unnamed: C25.2, U4.4 (CNEG)
unnamed: C25.1, U4.6 (CPOS)
unnamed: R6.1, U5.5 (PROG)
unnamed: R12.2, U11.S3 (CLK)
unnamed: R13.2, U11.S6 (I/O)
unnamed: R11.2, U11.S2 (RST)
unnamed: R14.2, U12.2 (A1)
unnamed: R15.2, U12.3 (A2)
PWRKEY: U1.17 (GPIO14), U9.39 (PWRKEY)
RFM_CS: U1.28 (GPIO17), U6.5 (NSS)
RFM_RST: U1.31 (GPIO20), U6.6 (RESET)
RF_ANT: J7.1 (In), U9.32 (RF_ANT)
RTC_BAT: BT1.1 (+), Q2.3 (D), U10.3 (VBAT)
RTC_MFP1: U1.4 (GPIO2), U10.7 (MFP), U13.B4 (INTA)
RTC_MFP2: U1.5 (GPIO3), U13.A4 (INTB)
RX0: U1.3 (GPIO1), U9.1 (UART1_TXD)
RX1: J4.5, U1.12 (GPIO9)
SCL: J4.14, U1.7 (GPIO5), U10.6 (SCL), U12.6 (SCL), U13.A3 (SCL)
SDA: J4.12, U1.6 (GPIO4), U10.5 (SDA), U12.5 (SDA), U13.B3 (SDA)
SIM_DTR: U1.18 (GPIO15), U9.6 (UART1_DTR)
SPI_CK: J4.11, U1.29 (GPIO18), U6.4 (SCK)
SPI_CS: J4.13, U1.32 (GPIO21)
SWCLK: J5.1, U1.24 (SWCLK)
SWD: J5.3, U1.25 (SWD)
TX0: U1.2 (GPIO0), U9.2 (UART1_RXD)
TX1: J4.3, U1.11 (GPIO8)
USB+: J2.A6 (D+_A), J2.B6 (D+_B), R1.2
USB-: J2.A7 (D-_A), J2.B7 (D-_B), R2.2
VBAT_SAMPLE: R17.2, R18.1, U1.38 (GPIO26_ADC0)
VBUS: C21.1, D2.2 (A), J2.A4_B9 (VBUS), J2.B4_A9 (VBUS__1), J4.1, J8.2, Q1.1 (G), R7.2, R8.1, U5.4 (V_{DD})

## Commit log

2024-01-19 added all the stuff!
    [CURVY_V1.kicad_pcb, CURVY_V1_2.kicad_pcb, node_v1.kicad_pcb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]
2024-03-02 v1 should be organized and complete and up to date. v2 was lost in an rm accident
    [node_v1.kicad_pcb]
2024-03-02 created v3 project, imported v1 schematic to be majorly updated
    [node_v3.kicad_pcb, node_v3.kicad_sch]
2024-03-02 added missing grounds
    [node_v3.kicad_sch]
2024-03-08 replaced pico with rp2040
    [freerouting.dsn, node_v3.kicad_pcb, node_v3.kicad_sch]
2024-03-23 moved stuff around, replaced headers, usb, footprints, started pcb
    [node_v1.kicad_sch, node_v3.kicad_pcb, node_v3.kicad_sch]
2024-03-24 finished? the pcb design - need to look into sd card stuff first
    [node_v3.kicad_pcb, node_v3.kicad_sch]
2024-03-25 not finished yet
    [node_v3.kicad_pcb, node_v3.kicad_sch]
2024-03-31 fixed the rfm footprint, fixed via sizes. need to adjust some vias to be bigger
    [node_v1.csv, node_v3.kicad_pcb, node_v3.kicad_sch]
2024-04-03 minor trace changes
    [node_v3.kicad_pcb]
2024-04-11 finalized pcb v3, added silkscreen and all and fixed some issues found in the drc
    [node_v3.kicad_pcb]
2024-05-25 v3.1 begin
    [node_v3.kicad_pcb, node_v3_1.kicad_pcb, node_v3_1.kicad_sch]
2024-05-27 minor adjustments
    [node_v3_1.kicad_sch]
2024-05-28 started pcb
    [node_v3_1.kicad_pcb, node_v3_1.kicad_sch]
2024-05-28 finished layout(probably)
    [node_v3_1.kicad_pcb]
2024-06-04 ready to order(probably)
    [node_v3.kicad_pcb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]
2024-06-10 created kicad drawings
    [915-yagi.kicad_pcb, 915-yagi.kicad_sch]
2024-07-30 begin v4
    [mcu.kicad_sch, node_v4_0.kicad_pcb, node_v4_0.kicad_sch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]
2024-07-30 converted v4 to different format and started the schematic(from scratch again)
    [comms.kicad_sch, connections.kicad_sch, mcu.kicad_sch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]
2024-08-10 more tracing, added RFM, added SIM, built power systems. converted to star ground
    [node_v4_0.kicad_pcb, peripherals.kicad_sch, power.kicad_sch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]
2024-08-13 lots of stuff
    [comms.kicad_sch, connections.kicad_sch, node_v4_0.kicad_pcb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]
2024-08-13 placed everything in the sim version
    [node_v4_0.kicad_pcb, node_v4_0_1.kicad_pcb]
2024-08-13 added footprint
2024-08-13 so much
    [comms.kicad_sch, connections.kicad_sch, node_v4_0.kicad_pcb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]
2024-08-13 placed power supplies
    [node_v4_0.kicad_pcb]
2024-08-13 finished laying out the board
    [node_v4_0.kicad_pcb, peripherals.kicad_sch, power.kicad_sch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]
2024-08-14 most routing done
    [connections.kicad_sch, node_v4_0.kicad_pcb, peripherals.kicad_sch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]
2024-08-15 added vin for solar/charge, more minor fixes
    [connections.kicad_sch, node_v4_0.kicad_pcb]
2024-08-15 moved reset button to make space for vin jst connector
    [BOM.ods, connections.kicad_sch, node_v4_0.kicad_pcb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]
2024-08-20 extended pads on RP2040 footprint for easier soldering by hand
2024-08-20 renamed directories for proper organization, updated readme
    [BOM.ods, comms.kicad_sch, connections.kicad_sch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]
2024-08-20 renamed more directories and files
    [BOM.ods, comms.kicad_sch, connections.kicad_sch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]
2024-08-20 remove kicad-libs to put them in their own repository
2024-08-25 updated to v4.1.0 - separate uart0 and 1 for SIM7080G / pinouts, add PWRKEY pin, add 5v control line, replace 32khz crystal caps with 0603. minor adjustments to component placement.
    [BOM.ods, comms.kicad_sch, connections.kicad_sch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]
2024-09-23 small changes to 4.1.1 routing
    [connections.kicad_sch, node_v4_1_0.kicad_sch, node_v4_1_1.kicad_pcb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]
2025-01-03 created v5, started changing parts over to JLC preferred
    [BOM.ods, comms.kicad_sch, connections.kicad_sch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]
2025-01-08 updated layout
    [connections.kicad_sch, node_v5_0_0.kicad_pcb, peripherals.kicad_sch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]
2025-01-08 lots of routing
    [node_v5_0_0.kicad_pcb]
2025-01-08 drc time
    [node_v5_0_0.kicad_pcb]
2025-01-08 finished layout and routing?
    [node_v5_0_0.kicad_pcb]
2025-01-09 updated layout of silkscreen, added labels and qr codes
    [node_v5_0_0.kicad_pcb]
2025-03-23 moved stuff around
    [2024-03-15.kicad_pcb, 2024-03-15.kicad_sch, 915-yagi.kicad_pcb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]
2025-03-23 updating kicad-libs submodule stuff
2025-03-23 removed nodes prior to V5 and moved them to a separate repo for deprecated designs
    [2024-03-15.kicad_pcb, 2024-03-15.kicad_sch, BOM.ods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]
2025-05-21 i should have made this more than one commit but: 1) started poking around in v5 to find and solve a sim card problem, forgot about it and moved on 2) created v6, modified the schematic somewhat, rem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
    [connections.kicad_sch, node-v6.kicad_pcb, node-v6.kicad_sch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]
2025-05-23 finished initial routing
    [node_v6_0_0.kicad_pcb]
2025-05-23 added silkscreens, fixed missing caps on RP2040 XTAL
    [node_v6_0_0.kicad_pcb]
2025-05-23 moved SWD pads, confirmed DRC ok
    [node_v6_0_0.kicad_pcb]
2025-06-02 moved v6.0.1 to v6.1.0, which is cancelled, and laid out (most of) board for v6.2.0 + began routing
    [connections.kicad_sch, node_v6_1_0.kicad_pcb, node_v6_1_0.kicad_sch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]
2025-06-03 finished layout v6.2
    [connections.kicad_sch, node_v6_2_0.kicad_pcb, power.kicad_sch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]
2025-06-03 finished routing; todo: labels and silkscreen, final review
    [node_v6_2_0.kicad_pcb, rp2040.kicad_sch]
2025-06-04 added zener diode for overvoltage protection on vbus, small routing adjustments, silkscreen component labels
    [node_v6_2_0.kicad_pcb, power.kicad_sch, rp2040.kicad_sch]
2025-06-04 finish silkscreen and verification
    [node_v6_2_0.kicad_pcb]
2025-07-02 demo board
    [pico2-demo.kicad_pcb, pico2-demo.kicad_sch]
2026-01-12 move some stuff around
    [915-yagi.kicad_pcb, 915-yagi.kicad_sch, yagi.kicad_pcb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]
2026-03-06 update kicad libs
2026-03-31 analysis and notation of major components, power consumption, capacitor types, temperature tolerances
    [connections.kicad_sch, node_v7_0_0.kicad_pcb, node_v7_0_0.kicad_sch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]
